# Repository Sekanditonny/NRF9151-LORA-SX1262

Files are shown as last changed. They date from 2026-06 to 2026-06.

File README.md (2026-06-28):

## 1. Overview

This design is a production-optimized modification of the open-source nRF9151 Feather platform, tailored for animal tracking applications.

The system integrates:

- Cellular (NTN/LTE-M/NB-IoT) + GPS via nRF9151
- LoRa communication# Animal Tracker PCB — nRF9151 + SX1262
 via SX1262
- Dual battery support (LiPo + Solar OR LiSOCl₂)
- Ultra-low power operation
- Compact form factor (≤ 50.8mm × 22.86mm)

All development-board-specific and non-essential components have been removed to improve cost, efficiency, and manufacturability.

---

## 2. Removed Components

The following features from the original Feather design are excluded:

- RP2040 co-processor
- USB-C interface
- External NOR Flash (Winbond 4MB)
- Non-essential push buttons (only Reset retained)
- QWIIC connector

---

## 3. Core Functional Blocks

### 3.1 Main Processing Unit

**nRF9151 SiP**

- Integrated LTE-M / NB-IoT / NTN modem
- Integrated GPS
- Main MCU for system control
- Interfaces with LoRa module and power control logic

### 3.2 LoRa Communication

**SX1262** (SMD 16×16mm module)

- SPI-connected to nRF9151
- Controlled via GPIO (including power gating)
- External U.FL antenna connector
- Internal RF matching (no external matching network required)
- Optimized for low-cost (~$2.8) and long-range communication

---

## 4. Power Architecture

### 4.1 Dual Battery Support

The system supports two mutually exclusive power configurations:

**LiPo Battery (Rechargeable)**
- Charged via solar input
- Managed by CN3165 solar charge controller

**LiSOCl₂ Battery (Primary)**
- Non-rechargeable
- Used for ultra-long-life deployments

### 4.2 Power Path Management

**LTC4412 Ideal Diode Controller**

- Automatically selects active power source
- Prevents reverse current
- Ensures seamless switching between battery types

### 4.3 Voltage Regulation Strategy

Instead of a PMIC (e.g., nPM1300), the design uses:

- Two buck regulators (Master + Slave)
- Controlled using RC timing + PGOOD logic
- Eliminates need for external microcontroller for sequencing

---

## 5. Power Sequencing (Critical Design)

The system uses RC-based timing ("power inertia") to meet nRF9151 strict requirements:

- VDD (core) must power ON first and OFF last
- VDD_GPIO must power OFF first

### 5.1 Master Rail (Main 3.3V – Core Supply)

**Components:**
- 100kΩ resistor
- 10µF capacitor

**Behavior:**
- Startup delay: ~700ms
- Shutdown delay: ~1000ms

**Purpose:**
- Provides stable core voltage
- Allows LTE modem network detach, safe flash memory writes, and system state preservation

### 5.2 Slave Rail (GPIO Supply – Fast Rail)

**Components:**
- 100kΩ pull-down
- 10nF capacitor

**Behavior:**
- Startup: activates after master reaches ~95%
- Shutdown: discharges in ~1ms

**Purpose:**
- Ensures GPIO power drops before core power
- Prevents back-powering through I/O pins

---

## 6. Solar Charging System

**CN3165 Solar Charge Controller**

- Handles LiPo charging from solar panel
- Efficient energy harvesting
- Supports autonomous field deployment
- Protects nRF9151 integrity

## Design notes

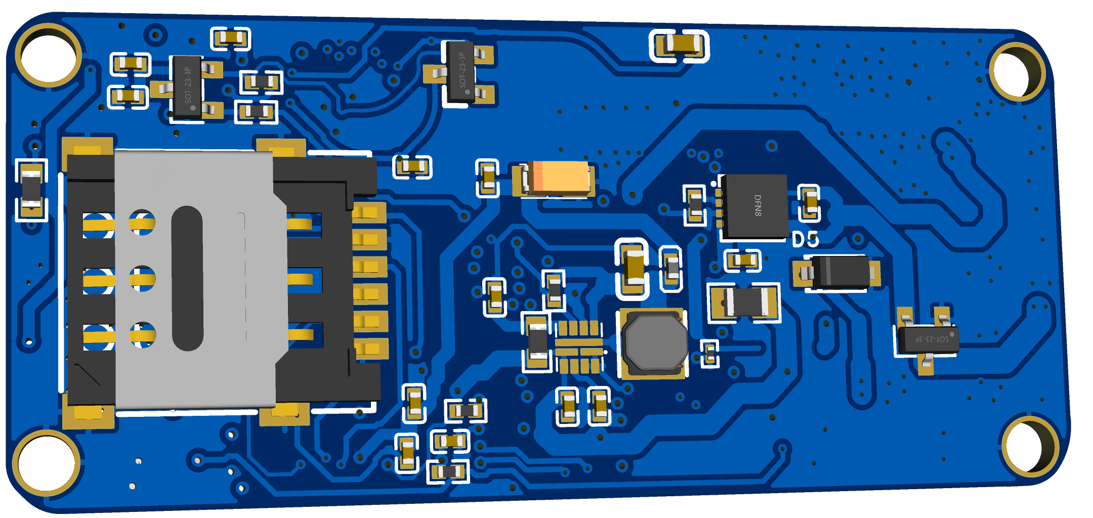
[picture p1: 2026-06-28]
3D_PCB1_2026-06-28 (1).png

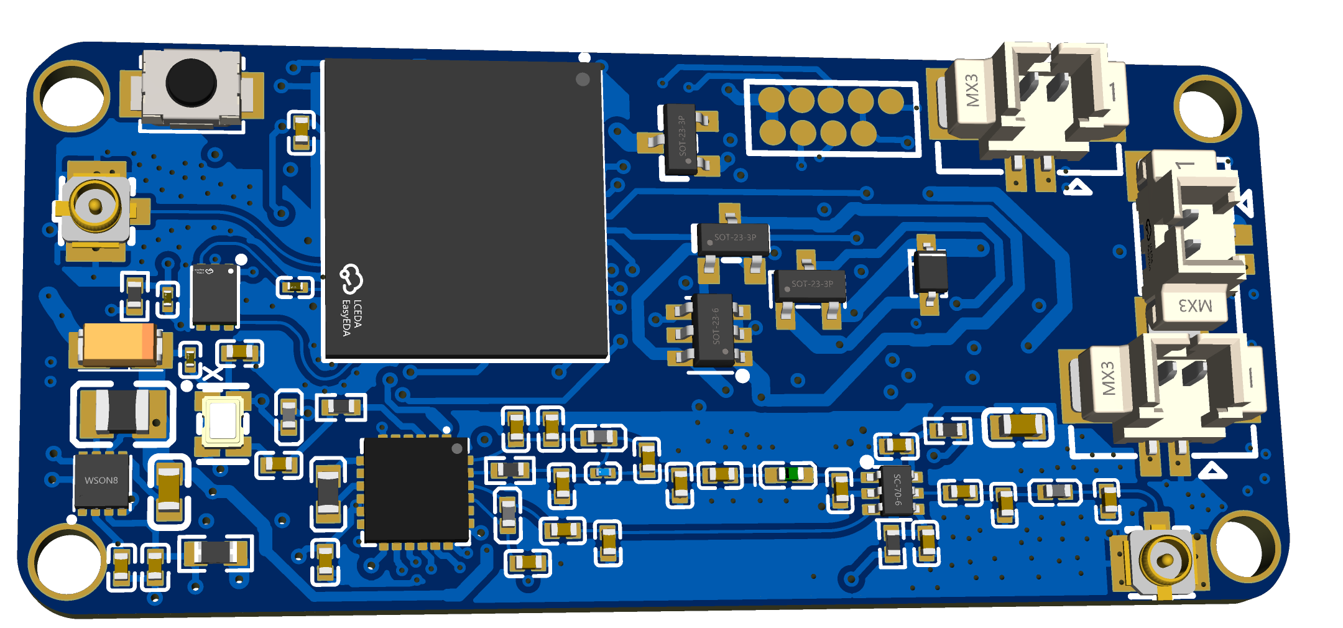
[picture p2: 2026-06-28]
3D_PCB1_2026-06-28 (2).png

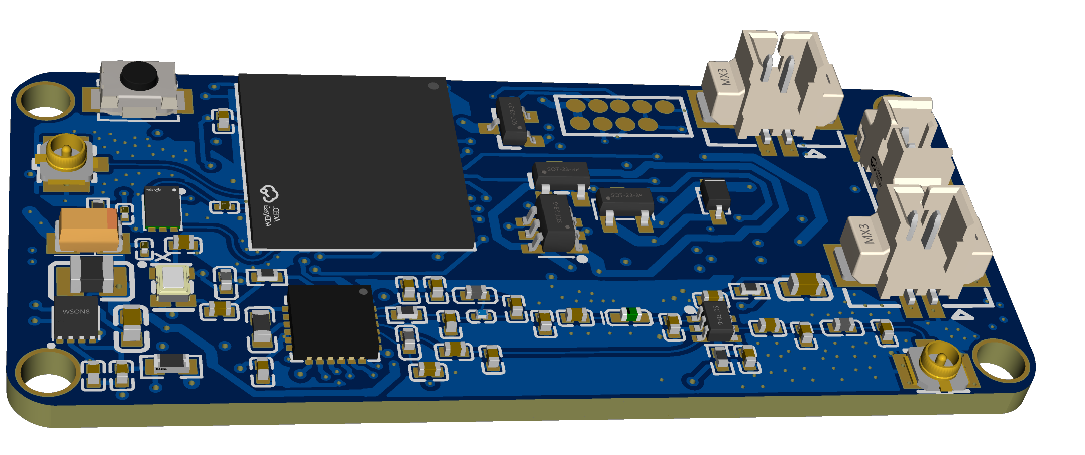
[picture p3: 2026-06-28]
3D_PCB1_2026-06-28.png

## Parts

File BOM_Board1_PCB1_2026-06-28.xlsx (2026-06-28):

No. | Quantity | Designator | Footprint | Value | Manufacturer Part | Manufacturer | Supplier Part | Supplier | JLCPCB Price | LCSC Price | Category | Unique ID | Name | Device
1 | 1 | C3 | C0402 | 15pF | 0402CG150J500NT | FH(风华) | C1548 | LCSC | 0.0013 |  | Capacitors:Multilayer Ceramic Capacitors MLCC - SMD/SMT | gge115 | 15pF | 0402CG150J500NT
2 | 4 | C7,C13,C18,C43 | C0402 | 10uF | CL05A106MQ5NUNC | SAMSUNG(三星) | C15525 | LCSC | 0.0045 |  | Capacitors:Multilayer Ceramic Capacitors MLCC - SMD/SMT | gge118,gge123,gge132,gge134 | 10uF | CL05A106MQ5NUNC
3 | 2 | C12,C17 | C0402 | 10nF | 0402B103K500NT | FH(风华) | C1524 | LCSC | 0.0006 |  | Capacitors:Multilayer Ceramic Capacitors MLCC - SMD/SMT | gge121,gge130 | 10nF | 0402B103K500NT
4 | 2 | C14,C15 | C0603 | 22uF | GRM188R60J226MEA0D | muRata(村田) | C77042 | LCSC | 0.0108 |  | Capacitors:Multilayer Ceramic Capacitors MLCC - SMD/SMT | gge124,gge125 | 22uF | GRM188R60J226MEA0D
5 | 2 | C41,C42 | C0402 | 10uF | CL05A106MP5NUNC | SAMSUNG(三星) | C315248 | LCSC | 0.0175 |  | Capacitors:Multilayer Ceramic Capacitors MLCC - SMD/SMT | gge64,gge65 | 10uF | CL05A106MP5NUNC_C315248
6 | 4 | C44,C48,C49,C57 | C0402 | 100nF | CL05B104KO5NNNC | SAMSUNG(三星) | C1525 | LCSC | 0.0012 |  | Capacitors:Multilayer Ceramic Capacitors MLCC - SMD/SMT | gge138,gge142,gge143,gge160 | 100nF | CL05B104KO5NNNC
7 | 3 | C45,C46,C47 | C0402 | 4.7uF | C1005X5R0J475MTJ00E | TDK | C23687 | LCSC | 0.0085 |  | Capacitors:Multilayer Ceramic Capacitors MLCC - SMD/SMT | gge139,gge140,gge141 | 4.7uF | C1005X5R0J475MTJ00E
8 | 2 | C50,C51 | CASE-A_3216 | 10uF | TAJA106K010RNJ | Kyocera AVX | C7177 | LCSC | 0.0252 |  | Capacitors:Tantalum Capacitors | gge145,gge146 | 10uF | TAJA106K010RNJ
9 | 1 | C52 | C0201 | 15pF | 0201CG150J500NT | FH(风华) | C64554 | LCSC | 0.0002 |  | Capacitors:Multilayer Ceramic Capacitors MLCC - SMD/SMT | gge147 | 15pF | 0201CG150J500NT
10 | 2 | C53,C54 | C0201 | 100nF | CL03A104KP3NNNC | SAMSUNG(三星) | C49062 | LCSC | 0.0011 |  | Capacitors:Multilayer Ceramic Capacitors MLCC - SMD/SMT | gge149,gge150 | 100nF | CL03A104KP3NNNC
11 | 1 | C56 | C0402 | 1nF | 0402CG102J500NT | FH(风华) | C53547 | LCSC | 0.0028 |  | Capacitors:Multilayer Ceramic Capacitors MLCC - SMD/SMT | gge157 | 1nF | 0402CG102J500NT
12 | 4 | C76,C81,C83,C85 | C0402 | 1nF | 0402B102K500NT | FH(风华) | C1523 | LCSC | 0.0013 |  | Capacitors:Multilayer Ceramic Capacitors MLCC - SMD/SMT | gge195,gge200,gge202,gge204 | 1nF | 0402B102K500NT
13 | 1 | C88 | C0402 | 10pF | 0402CG100J500NT | FH(风华) | C1545 | LCSC | 0.001 |  | Capacitors:Multilayer Ceramic Capacitors MLCC - SMD/SMT | gge214 | 10pF | 0402CG100J500NT
14 | 1 | C89 | C0402 | 470nF | CL05A474KP5NNNC | SAMSUNG(三星) | C47339 | LCSC | 0.0014 |  | Capacitors:Multilayer Ceramic Capacitors MLCC - SMD/SMT | gge216 | 470nF | CL05A474KP5NNNC
15 | 1 | C90 | C0402 | 47nF | GRM155R71C473KA01D | muRata(村田) | C77012 | LCSC | 0.001 |  | Capacitors:Multilayer Ceramic Capacitors MLCC - SMD/SMT | gge217 | 47nF | GRM155R71C473KA01D
16 | 1 | C91 | C0402 | 47pF | GRM1555C1H470JA01D | muRata(村田) | C76970 | LCSC | 0.0013 |  | Capacitors:Multilayer Ceramic Capacitors MLCC - SMD/SMT | gge218 | 47pF | GRM1555C1H470JA01D
17 | 1 | C92 | C0402 | 3pF | GJM1555C1H3R0BB01D | muRata(村田) | C88891 | LCSC | 0.0038 |  | Capacitors:Multilayer Ceramic Capacitors MLCC - SMD/SMT | gge222 | 3pF | GJM1555C1H3R0BB01D
18 | 1 | C93 | C0402 | 5.6pF | GRM1555C1H5R6BA01D | muRata(村田) | C76976 | LCSC | 0.0009 |  | Capacitors:Multilayer Ceramic Capacitors MLCC - SMD/SMT | gge223 | 5.6pF | GRM1555C1H5R6BA01D
19 | 2 | C94,C98 | C0402 | 39pF | GCM1555C1H390JA16D | muRata(村田) | C343867 | LCSC | 0.0013 |  | Capacitors:Multilayer Ceramic Capacitors MLCC - SMD/SMT | gge224,gge224_1 | 39pF | GCM1555C1H390JA16D
20 | 2 | C95,C96 | C0402 | 1.8pF | GJM1555C1H1R8BB01D | muRata(村田) | C76902 | LCSC | 0.0036 |  | Capacitors:Multilayer Ceramic Capacitors MLCC - SMD/SMT | gge226,gge226_1 | 1.8pF | GJM1555C1H1R8BB01D
21 | 1 | C97 | C0402 | 2.4pF | GJM1555C1H2R4BB01D | muRata(村田) | C88888 | LCSC | 0.0031 |  | Capacitors:Multilayer Ceramic Capacitors MLCC - SMD/SMT | gge228 | 2.4pF | GJM1555C1H2R4BB01D
22 | 2 | C99,C100 | C0402 | 3.3pF | GJM1555C1H3R3BB01D | muRata(村田) | C76906 | LCSC | 0.0047 |  | Capacitors:Multilayer Ceramic Capacitors MLCC - SMD/SMT | gge229,gge230 | 3.3pF | GJM1555C1H3R3BB01D
23 | 2 | C101,C102 | C0603 | NC |  |  |  |  |  | 0.0210 | Capacitors:Multilayer Ceramic Capacitors MLCC - SMD/SMT | gge235,gge236 | NC | CAP_0603
24 | 1 | CARD2 | SIM-SMD_SIM-1305-6P |  | SNO-1305-B | SOFNG(硕方) | C111371 | LCSC | 0.0332 |  | Connectors:SIM Card Connectors | gge240 | SNO-1305-B | SNO-1305-B
25 | 3 | CN4,CN5,CN6 | CONN-SMD_2P-P1.25_A1251WV-S-2P |  | A1251WV-S-2P | CJT(长江连接器) | C225104 | LCSC | 0.0116 |  | Connectors:Wire To Board Connector | gge241,gge242,gge243 | A1251WV-S-2P | A1251WV-S-2P
26 | 1 | D5 | SOD-123_L2.8-W1.8-LS3.7-RD |  | MBR120LSF | SHIKUES(时科) | C130880 | LCSC | 0.0066 |  | Diodes:Schottky Diodes | gge113 | MBR120LSF | MBR120LSF
27 | 1 | D6 | SOD-323_L1.8-W1.3-LS2.5-RD |  | BZT52C7V5S | YFW(佑风微) | C5270778 | LCSC | 0.0024 |  | Diodes:Zener Diodes | gge246 | BZT52C7V5S | BZT52C7V5S_C5270778
28 | 1 | L3 | IND-SMD_L3.0-W3.0_SWPA3010S | 1uH | SWPA3015S1R0NT | Sunlord(顺络) | C43388 | LCSC | 0.0068 |  | Inductors, Coils, Chokes:Power Inductors | gge122 | 1uH | SWPA3015S1R0NT
29 | 1 | L4 | L0806 | 2.2uH | MLP2016V2R2MT0S1 | TDK | C307746 | LCSC | 0.0112 |  | Inductors, Coils, Chokes:Inductors (SMD) | gge127 | 2.2uH | MLP2016V2R2MT0S1
30 | 1 | L20 | L0402 | 47nH | LQG15HH47NH02D | muRata(村田) | C2042001 | LCSC | 0.0059 |  | Inductors, Coils, Chokes:Inductors (SMD) | gge219 | 47nH | LQG15HH47NH02D
31 | 1 | L21 | L0201 | 2.5nH | LQP03HQ2N5B02D | muRata(村田) | C237441 | LCSC | 0.0059 |  | Inductors, Coils, Chokes:Inductors (SMD) | gge221 | 2.5nH | LQP03HQ2N5B02D
32 | 1 | L22 | L0402-R-RD | 4.7nH | LQG15HS4N7S02D | muRata(村田) | C86065 | LCSC | 0.0035 |  | Inductors, Coils, Chokes:Inductors (SMD) | gge225 | 4.7nH | LQG15HS4N7S02D
33 | 1 | L23 | L0402 | 15nH | LQG15HS15NJ02D | muRata(村田) | C86059 | LCSC | 0.0036 |  | Inductors, Coils, Chokes:Inductors (SMD) | gge227 | 15nH | LQG15HS15NJ02D
34 | 1 | L24 | L0402 | 9.1nH | LQG15HN9N1J02D | muRata(村田) | C113059 | LCSC | 0.0017 |  | Inductors, Coils, Chokes:Inductors (SMD) | gge231 | 9.1nH | LQG15HN9N1J02D
35 | 2 | L26,L27 | L0402 |  | CBW100505U101T | FH(风华) | C124089 | LCSC | 0.0008 |  | Filters:Ferrite Beads | gge247,gge248 | CBW100505U101T | CBW100505U101T
36 | 3 | Q1,Q2,Q3 | SOT-23_L2.9-W1.3-P1.90-LS2.4-BR |  | AO3407A | UMW(友台半导体) | C347478 | LCSC | 0.0051 |  | Transistors/Thyristors:MOSFETs | gge5,gge6,gge7 | AO3407A | AO3407A_C347478
37 | 2 | Q6,Q8 | SOT-23-3_L2.9-W1.3-P1.90-LS2.4-BR |  | SI2301 | Hottech(合科泰) | C181086 | LCSC | 0.0037 |  | Transistors/Thyristors:MOSFETs | gge62,gge62_1 | SI2301 | SI2301_C181086
38 | 1 | Q7 | SOT-23-3_L2.9-W1.3-P1.90-LS2.4-BR |  | MMBT3904 | ST(先科) | C84104 | LCSC | 0.0015 |  | Transistors/Thyristors:Bipolar (BJT) | gge135 | MMBT3904 | MMBT3904_C84104
39 | 3 | R8,R9,R13 | R0603 | 100kΩ | 0603WAF1003T5E | UNI-ROYAL(厚声) | C25803 | LCSC | 0.0003 |  | Resistors:Chip Resistor - Surface Mount | gge126,gge128,gge131 | 100kΩ | 0603WAF1003T5E
40 | 2 | R11,R53 | R0402 | 10kΩ | 0402WGJ0103TCE | UNI-ROYAL(厚声) | C25531 | LCSC | 0.0002 |  | Resistors:Chip Resistor - Surface Mount | gge129,gge151 | 10kΩ | 0402WGJ0103TCE
41 | 1 | R46 | R0201 | 10kΩ | RC0201FR-0710KL | YAGEO(国巨) | C106225 | LCSC | 0.0002 |  | Resistors:Chip Resistor - Surface Mount | UNIQUER6_1 | 10kΩ | RC0201FR-0710KL
42 | 2 | R47,R51 | R0402 | 2kΩ | RC0402FR-072KL | YAGEO(国巨) | C60488 | LCSC | 0.0003 |  | Resistors:Chip Resistor - Surface Mount | gge66,gge66_1 | 2kΩ | RC0402FR-072KL
43 | 1 | R48 | R0805 | 470kΩ | 0805W8F4703T5E | UNI-ROYAL(厚声) | C17709 | LCSC | 0.0006 |  | Resistors:Chip Resistor - Surface Mount | gge133 | 470kΩ | 0805W8F4703T5E
44 | 1 | R49 | R0402 | 2.2kΩ | 0402WGF2201TCE | UNI-ROYAL(厚声) | C25879 | LCSC | 0.0002 |  | Resistors:Chip Resistor - Surface Mount | gge136 | 2.2kΩ | 0402WGF2201TCE
45 | 1 | R50 | R0402 | 22kΩ | 0402WGJ0223TCE | UNI-ROYAL(厚声) | C25547 | LCSC | 0.0001 |  | Resistors:Chip Resistor - Surface Mount | gge137 | 22kΩ | 0402WGJ0223TCE
46 | 1 | R52 | R0402 | 1MΩ | CR0402FF1004G | LIZ(丽智电子) | C100198 | LCSC | 0.0002 |  | Resistors:Chip Resistor - Surface Mount | gge148 | 1MΩ | CR0402FF1004G
47 | 1 | R57 | R0402 | 220Ω | 0402WGF2200TCE | UNI-ROYAL(厚声) | C25091 | LCSC | 0.0002 |  | Resistors:Chip Resistor - Surface Mount | gge215 | 220Ω | 0402WGF2200TCE
48 | 1 | R58 | R0402 | 0Ω | CRCW04020000Z0ED | VISHAY(威世) | C190119 | LCSC | 0.0005 |  | Resistors:Chip Resistor - Surface Mount | gge220 | 0Ω | CRCW04020000Z0ED
49 | 2 | R59,R60 | R0402 | 100Ω | 0402WGF1000TCE | UNI-ROYAL(厚声) | C25076 | LCSC | 0.0003 |  | Resistors:Chip Resistor - Surface Mount | gge232,gge233 | 100Ω | 0402WGF1000TCE
50 | 2 | RF2,RF3 | RF-SMD_FRF05002-JSS103M | 6GHz | U.FL-R-SMT-1(80) | HRS(广濑) | C88374 | LCSC | 0.0161 |  | Connectors:Coaxial Connectors (RF) | gge90_1,gge90_2 | 6GHz | U.FL-R-SMT-1(80)_C88374
51 | 1 | SW2 | SW-SMD_L3.9-W3.0-P4.45 |  | TS-1088-AR02016 | XUNPU(讯普) | C720477 | LCSC | 0.0083 |  | Switches:Tactile Switches | gge245 | TS-1088-AR02016 | TS-1088-AR02016
52 | 1 | U1 | LGA-113_L12.1-W11.1_NRF9151-LACA-R7 |  | nRF9151-LACA-R7 | Nordic Semicon | C22397843 | JLCPCB | 2.3949 |  |  | gge1 | nRF9151-LACA-R7 | NRF9151-LACA-R_C42236596
53 | 1 | U5 | SOT-23-6_L2.9-W1.6-P0.95-LS2.8-BL |  | LTC4412IS6#TRPBF | ADI(亚德诺) | C521306 | LCSC | 0.4951 |  | Motor Driver ICs:Gate Drivers | gge4 | LTC4412IS6#TRPBF | LTC4412IS6#TRPBF_C521306
54 | 1 | U8 | MCM-6_L2.3-W1.7-P0.54-TL-EP |  | SKY65723-81 | SKYWORKS | C2654196 | LCSC | 0.4199 |  | RF and Wireless:RF Amplifiers | gge114 | SKY65723-81 | SKY65723-81
55 | 1 | U9 | VQFN-11_L2.0-W2.0-P0.50-TL_TI_RWK |  | TPS6209733RWKR | TI(德州仪器) | C2071261 | LCSC | 0.237 |  | Power Management (PMIC):DC-DC Converters | gge119 | TPS6209733RWKR | TPS6209733RWKR
56 | 1 | U10 | WSON-8_L2.0-W2.0-P0.50-TL-EP |  | TPS62172DSGR | TI(德州仪器) | C59873 | LCSC | 0.1946 |  | Power Management (PMIC):DC-DC Converters | gge120 | TPS62172DSGR | TPS62172DSGR
57 | 1 | U11 | DFN-8_L3.0-W3.0-P0.50-BL-EP |  | CN3165 | CONSONANCE(上海如韵) | C559035 | LCSC | 0.0332 |  | Power Management (PMIC):Battery Management | gge106 | CN3165 | CN3165
58 | 1 | U13 | QFN-24_L4.0-W4.0-P0.50-BL-EP2.6 |  | SX1262IMLTRT | SEMTECH | C191341 | LCSC | 0.4798 |  | RF and Wireless:RF Transceiver ICs | gge152 | SX1262IMLTRT | SX1262IMLTRT
59 | 1 | U14 | SC-70-6_L2.2-W1.3-P0.65-LS2.1-BL |  | PE4259-63 | pSemi(游隼半导体) | C470892 | LCSC | 0.0935 |  | RF and Wireless:RF Switches | gge153 | PE4259-63 | PE4259-63
60 | 1 | U15 | L0603 | 15uH | CMI160808J150KT | FH(风华) | C394963 | LCSC | 0.0032 |  | Inductors, Coils, Chokes:Inductors (SMD) | gge213 | 15uH | CMI160808J150KT
61 | 1 | U16 | J CONNEXCO |  |  |  |  |  |  | 0.0210 | Connectors: | gge244 | {Symbol!} | J CONNEXTOR89
62 | 1 | X1 | OSC-SMD_4P-L2.0-W1.6-BL_1XXD | 32MHz | 1XXD32000MBA | KDS(大真空) | C253694 | LCSC | 0.1395 |  | Crystals, Oscillators, Resonators:Temperature Compensated Crystal Oscillators (TCXO) | gge154 | 32MHz | 1XXD32000MBA_C253694

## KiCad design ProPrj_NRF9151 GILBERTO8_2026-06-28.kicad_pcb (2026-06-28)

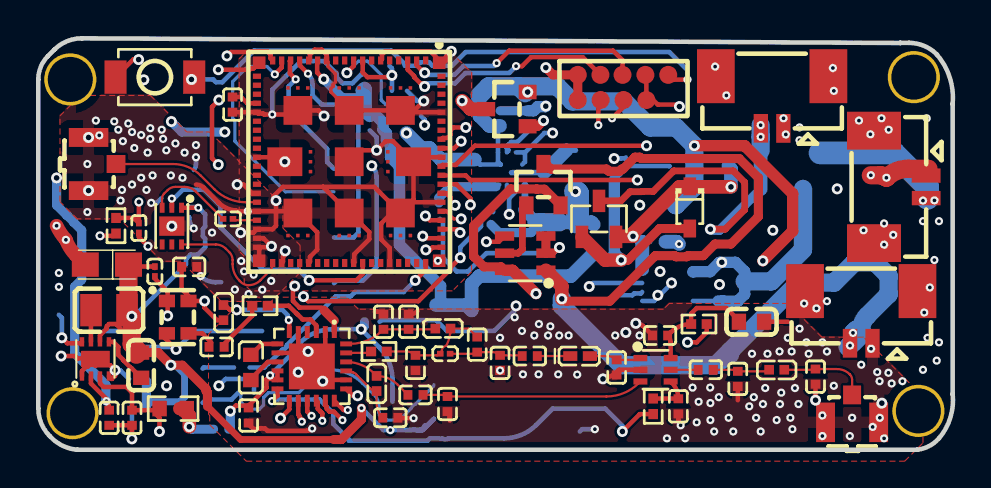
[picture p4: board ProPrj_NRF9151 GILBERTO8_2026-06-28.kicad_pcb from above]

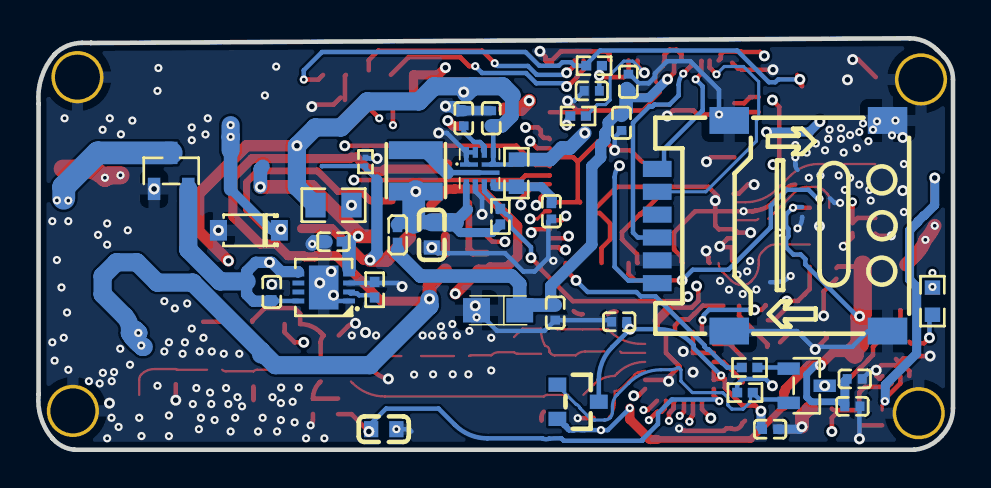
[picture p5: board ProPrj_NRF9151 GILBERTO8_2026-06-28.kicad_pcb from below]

Board: 4 copper layers, 50.8 x 22.9 mm, 94 parts (35 on the bottom side), 72 nets.

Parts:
C3, C7, C12, C13, C17, C18, C41, C42, C43, C44, C45, C46, C47, C48, C49, C56, C57, C76, C81, C83, C85, C88, C89, C90, C91, C92, C93, C94, C95, C96, C97, C98, C99, C100: C0402
C14, C15, C101, C102: C0603
C50, C51: CASE-A_3216
C52, C53, C54: C0201
CARD2: SIM-SMD_SIM-1305-6P
CN4, CN5, CN6: CONN-SMD_2P-P1.25_A1251WV-S-2P
D5: SOD-123_L2.8-W1.8-LS3.7-RD
D6: SOD-323_L1.8-W1.3-LS2.5-RD
L3: IND-SMD_L3.0-W3.0_SWPA3010S
L4: L0806
L20, L23, L24, L26, L27: L0402
L21: L0201
L22: L0402-R-RD
Q1, Q2, Q3: SOT-23_L2.9-W1.3-P1.90-LS2.4-BR
Q6, Q7, Q8: SOT-23-3_L2.9-W1.3-P1.90-LS2.4-BR
R8, R9, R13: R0603
R11, R47, R49, R50, R51, R52, R53, R57, R58, R59, R60: R0402
R46: R0201
R48: R0805
RF2, RF3: RF-SMD_FRF05002-JSS103M
SW2: SW-SMD_L3.9-W3.0-P4.45
U1: LGA-113_L12.1-W11.1_NRF9151-LACA-R7
U5: SOT-23-6_L2.9-W1.6-P0.95-LS2.8-BL
U8: MCM-6_L2.3-W1.7-P0.54-TL-EP
U9: VQFN-11_L2.0-W2.0-P0.50-TL_TI_RWK
U10: WSON-8_L2.0-W2.0-P0.50-TL-EP
U11: DFN-8_L3.0-W3.0-P0.50-BL-EP
U13: QFN-24_L4.0-W4.0-P0.50-BL-EP2.6
U14: SC-70-6_L2.2-W1.3-P0.65-LS2.1-BL
U15: L0603
U16: J CONNEXCO
X1: OSC-SMD_4P-L2.0-W1.6-BL_1XXD

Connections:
3.3V_SYS_2A: C14.2, L3.2, L27.2, R11.1, R50.2, R53.1, U9.3, U16.1, U16.6
$1N5599: C12.2, U9.9
$1N5840: L3.1, U9.2
$1N6280: C15.2, U10.5
$1N6332: R8.2, U10.8
$1N6408: L4.2, U10.7
$1N6706: C18.2, R9.1, U9.6
$1N7225: CN4.2, Q8.3
$1N7651: CN5.2, D5.1, Q6.3
$1N7654: D6.2, Q6.1, R46.1
$1N7658: R47.2, U11.2
$1N7845: CN6.2, Q1.3, U5.1
$1N7884: Q1.1, U5.5
$1N7906: Q2.1, R48.1, U5.4
$1N8450: Q7.1, R49.2
$1N10304: Q3.1, Q7.2, R50.1
$1N10488: C44.2, R51.2, U1.9
$1N10935: C45.2, U1.24
$1N12604: C52.1, U8.3
$1N15358: R57.2, U13.3
$1N15364: C88.2, R57.1
$1N15368: C88.1, X1.3
$1N15674: U13.7, U15.2
$1N15679: U13.9, U15.1
$1N16005: R58.1, U13.23
$1N16052: C90.2, C91.2, L20.2, U13.24
$1N16301: C76.2, C92.1, L20.1, L21.1, R58.2
$1N16358: C92.2, C93.2, C94.1, L21.2
$1N16409: C94.2, L22.1
$1N16412: C95.2, L22.2, U14.1
$1N16561: C96.2, L23.1, U13.21
$1N16740: C81.2, C97.2, U14.3
$1N16747: C97.1, L23.2, U13.22
$1N17013: C85.2, C102.2, R59.2, U14.6
$1N17155: C98.1, U14.5
$1N17206: C98.2, C99.2, L24.1
$1N17209: C100.2, L24.2, RF3.1
$1N17526: C56.1, L26.1, X1.4
$1N35658: C83.2, R60.2, U14.4
ANT_SW: R59.1, U1.73
BUSY: U1.68, U13.14
COEX0: C53.1, R52.1, U1.52, U8.2
DEB_RX: U1.69, U16.7
DEB_TX: U1.70, U16.8
DI01: U1.72, U13.13
DI03: L26.2, U13.6
DIO2: C101.1, R60.1, U13.12
ENABLE: R53.2, U1.10
ENABLE_3.3VGPIO: C17.2, R11.2, R13.1, U9.5, U10.3
GND: C3.1, C7.1, C12.1, C13.1, C14.1, C17.1, C18.1, C41.1, C42.1, C43.2, C44.1, C45.1, C46.2, C47.2, C48.1, C49.1, C50.2, C51.2, C53.2, C54.2, C56.2, C57.2, C76.1, C81.1, C83.1, C85.1, C89.1, C90.1, C91.1, C93.1, C95.1, C96.1, C99.1, C100.1, C101.2, C102.1, CARD2.7, CARD2.8, CARD2.9, CARD2.10, CARD2.C5, CN4.1, CN4.3, CN4.4, CN5.1, CN5.3, CN5.4, CN6.1, CN6.3, CN6.4, D5.2, Q7.3, Q8.1, R13.2, R46.2, R47.1, R52.2, RF2.2, RF2.3, RF3.2, RF3.3, SW2.2, U1.1, U1.7, U1.13, U1.15, U1.20, U1.25, U1.30, U1.34, U1.36, U1.38, U1.39, U1.40, U1.41, U1.43, U1.46, U1.51, U1.55, U1.60, U1.66, U1.71, U1.76, U1.105, U1.106, U1.107, U1.108, U1.109, U1.110, U1.111, U1.112, U1.113, U5.2, U5.3, U8.7, U9.1, U9.4, U9.10, U9.11, U10.1, U10.4, U10.9, U11.1, U11.3, U11.9, U13.2, U13.5, U13.8, U13.20, U13.25, U14.2, U16.4, U16.9, X1.1, X1.2
GPIO3V3_LORA_500MA: C15.1, C47.1, C48.2, C51.1, C54.1, L4.1, Q3.2, R8.1, U1.65, U8.1, U10.6
LORA_VOLTAGE_ENABLE: R49.1, U1.59
MISO: U1.62, U13.16
MOSI: U1.64, U13.17
NRESET: U1.67, U13.15
NRF9151-VDD: C3.2, C46.1, C49.2, C50.1, L27.1, U1.14
NSS: U1.61, U13.19
RESET: R51.1, SW2.1, U16.5
RF_ANT: RF2.1, U1.35
RF_AUX: C52.2, U1.37
RF_GPS: U1.42, U8.6
SCK: U1.63, U13.18
SIM_CLK: CARD2.C3, U1.18
SIM_IO: CARD2.C7, U1.17
SIM_RST: CARD2.C2, U1.16
SIM_VCC: CARD2.C1, U1.19
SOLAR_PV: C41.2, D6.1, Q6.2, U11.4
SWDCLK: U1.3, U16.3
SWDIO: U1.4, U16.2
VBAT: C42.2, Q2.3, Q8.2, U11.5, U11.8
VDD_SX126: C43.1, C57.1, C89.2, Q3.3, U13.1, U13.10, U13.11
VIN: C7.2, C13.2, Q1.2, Q2.2, R9.2, R48.2, U5.6, U9.7, U9.8, U10.2
